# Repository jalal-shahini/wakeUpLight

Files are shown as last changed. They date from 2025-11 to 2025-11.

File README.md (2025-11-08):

# Wake up light

This is the circuit and code for a smart, super bight light that slowly brightens in the mornings to wake me up without an alarm.
The light can also be used as reading light at night with a timer to turn off automatically.
It features a 2004 LCD and a rotary encoder for user input.
The encoder has a calibrated debounce circuit and a schmitt-trigger for the cleanest possible signal.

An LED driver is required alongside this circuit.
I have decided to use a ZK-SJ20 to protect the LED from over current.
Max. LED power is 50 watts.
A CR2032 battery is required for the RTC to keep the time when the power is disconnected.

## To Do

* Since the device is connected to the wall outlet, energy efficiency was not of the highest concern. However, in feauture iterations, I will replace the linear voltage regulator with a buck converter.

**Disclaimer: The design is not yet ready for production. Therefore, the bom and positions files are not accurate.**

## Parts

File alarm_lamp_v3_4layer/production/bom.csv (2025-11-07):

Designator | Footprint | Quantity | Value | LCSC Part #
BT1 | BatteryHolder_MYOUNG_BS-07-A1BJ001_CR2032 | 1 | Battery_Cell | C5365915
C1, C10, C11, C2, C3, C4 | 0402 | 6 | 100 nF | C1525
C12 | 1206 | 1 | 2,2 uF | C50254
C5 | 0805 | 1 | 10 nF | C1710
C6, C7 | 0402 | 2 | 18 pF | C1549
C8 | 1206 | 1 | 22 uF | C1549
L1 | 0603 | 1 | 10 uH | C1035
R1 | 0603 | 1 | 330R | C23138
R10, R2, R6, R7, R8 | 0805 | 5 | 10 K | C17414
R11, R12, R3 | 0603 | 3 | 100K | C1002
R4, R5 | 0805 | 2 | 4.7k
R9 | 0805 | 1 | 100R | C17408
U1 | TQFP-32_7x7mm_P0.8mm | 1 | ATmega328P-A | C14877
U3 | SOIC-14_3.9x8.7mm_P1.27mm | 1 | 74HC14 | C5605
U4 | SOIC-16W_7.5x10.3mm_P1.27mm | 1 | DS3231M | C9866
U6 | WSON-10-1EP_2x3mm_P0.5mm_EP0.84x2.4mm_ThermalVias | 1 | TPS62177DQC | C91241
Y2 | Crystal_SMD_3225-4Pin_3.2x2.5mm | 1 | Crystal_GND24 | C2682774

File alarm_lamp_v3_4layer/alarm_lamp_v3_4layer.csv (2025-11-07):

Id | Designator | Footprint | Quantity | Designation | Supplier and ref
1 | BT1 | BatteryHolder_MYOUNG_BS-07-A1BJ001_CR2032 | 1 | Battery_Cell
2 | R4,R5 | R_0805_2012Metric | 2 | 4.7k
3 | R8,R10,R7,R2,R6 | R_0805_2012Metric | 5 | 10 K
4 | R12,R11,R3 | R_0603_1608Metric | 3 | 100K
5 | C11,C1,C4,C2,C10,C3 | C_0402_1005Metric | 6 | 100 nF
6 | C7,C6 | C_0402_1005Metric | 2 | 18 pF
7 | Y2 | Crystal_SMD_3225-4Pin_3.2x2.5mm | 1 | Crystal_GND24
8 | U1 | TQFP-32_7x7mm_P0.8mm | 1 | ATmega328P-A
9 | U4 | SOIC-16W_7.5x10.3mm_P1.27mm | 1 | DS3231M
10 | L1 | R_0402_1005Metric | 1 | 10 uH
11 | U6 | WSON-10-1EP_2x3mm_P0.5mm_EP0.84x2.4mm_ThermalVias | 1 | TPS62177DQC
12 | C12 | C_1206_3216Metric | 1 | 2,2 uF
13 | C5 | C_0805_2012Metric | 1 | 10 nF
14 | C8 | C_1206_3216Metric | 1 | 22 uF
15 | R9 | R_0805_2012Metric | 1 | 100R
16 | R1 | R_0603_1608Metric | 1 | 330R
17 | U3 | SOIC-14_3.9x8.7mm_P1.27mm | 1 | 74HC14

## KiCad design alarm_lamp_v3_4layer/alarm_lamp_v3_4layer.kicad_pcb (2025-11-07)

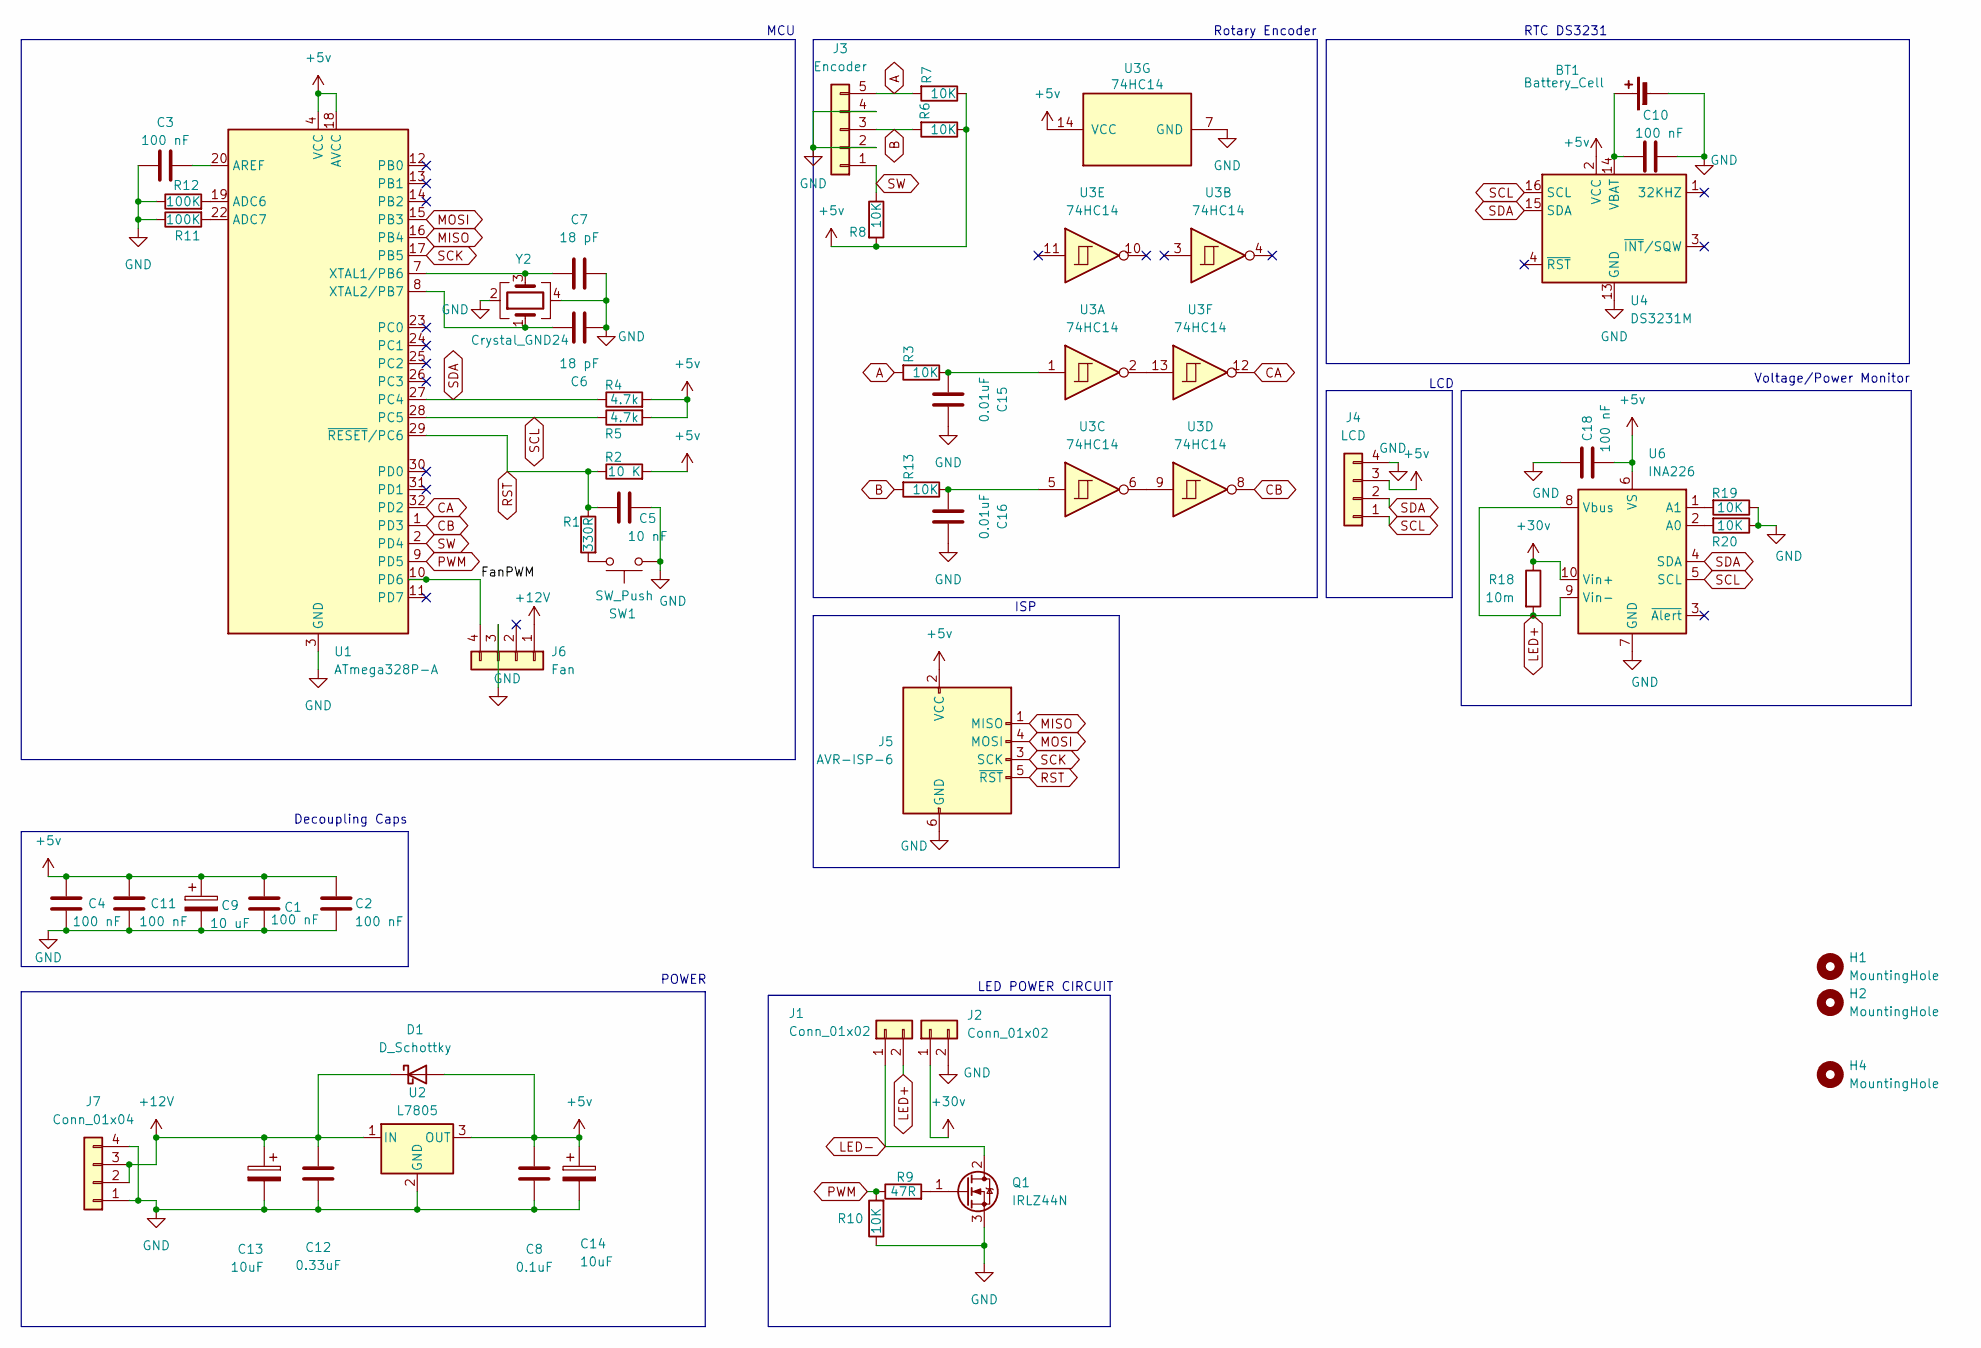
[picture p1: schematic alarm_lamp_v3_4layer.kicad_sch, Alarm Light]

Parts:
BT1: Battery_Cell; BatteryHolder_MYOUNG_BS-07-A1BJ001_CR2032; LCSC C5365915
C1, C4, C11, C18: 100 nF; C_0402_1005Metric; LCSC C1525
C2, C3: 100 nF; C_0603_1608Metric
C5: 10 nF; C_0603_1608Metric
C6, C7: 18 pF; C_0402_1005Metric; LCSC C1549
C8: 0.1uF; C_0603_1608Metric
C9: 10 uF; CP_Elec_4x5.3; LCSC C346925
C10: 100 nF; C_0402_1005Metric
C12: 0.33uF; C_0603_1608Metric
C13, C14: 10uF; CP_Elec_4x5.3; LCSC C346925
C15, C16: 0.01uF; C_0402_1005Metric
D1: D_Schottky; D_SOD-323; LCSC C191023
H1, H2, H4: MountingHole; MountingHole_3.2mm_M3
J1, J2: Conn_01x02; TerminalBlock_Phoenix_MKDS-1,5-2-5.08_1x02_P5.08mm_Horizont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
J3: Encoder; JST_XH_B5B-XH-A_1x05_P2.50mm_Vertical
J4: LCD; JST_XH_B4B-XH-A_1x04_P2.50mm_Vertical
J5: AVR-ISP-6; PinHeader_2x03_P2.54mm_Vertical
J6: Fan; JST_XH_B4B-XH-A_1x04_P2.50mm_Vertical
J7: Conn_01x04; TerminalBlock_Phoenix_MKDS-1,5-4-5.08_1x04_P5.08mm_Horizont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
Q1: IRLZ44N; TO-263-2; LCSC C19188232
R1: 330R; R_0603_1608Metric; LCSC C23138
R2: 10 K; R_0603_1608Metric; LCSC C17414
R3, R13: 10K; R_0402_1005Metric; LCSC C17414
R4, R5: 4.7k; R_0603_1608Metric
R6, R7, R8, R10: 10K; R_0603_1608Metric; LCSC C17414
R9: 47R; R_0603_1608Metric
R11, R12: 100K; R_0603_1608Metric; LCSC C25803
R18: 10m; R_2512_6332Metric
R19, R20: 10K; R_0603_1608Metric; LCSC C25804
SW1: SW_Push; SW_Push_1P1T_XKB_TS-1187A; LCSC C318884
U1: ATmega328P-A; TQFP-32_7x7mm_P0.8mm; LCSC C14877
U2: L7805; TO-263-2; LCSC C15077
U3: 74HC14; SOIC-14_3.9x8.7mm_P1.27mm; LCSC C5605
U4: DS3231M; SOIC-16W_7.5x10.3mm_P1.27mm; LCSC C9866
U6: INA226; VSSOP-10_3x3mm_P0.5mm; LCSC C2653835
Y2: Crystal_GND24; Crystal_SMD_3225-4Pin_3.2x2.5mm; LCSC C13738

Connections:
+5v: C1.1, C2.1, C4.1, C8.1, C9.1, C11.1, C14.1, C18.2, D1.2 (A), J4.3, J5.2 (VCC), R2.2, R4.2, R5.2, R6.1, R7.1, R8.2, U1.4 (VCC), U1.6 (VCC), U1.18 (AVCC), U2.3 (OUT), U3.14 (VCC), U4.2 (VCC), U6.6 (VS)
+12V: C12.1, C13.1, D1.1 (K), J6.1, J7.2, J7.3, U2.1 (IN)
+30v: J2.1, R18.1, U6.10 (Vin+)
/FanPWM: J6.4, U1.10 (PD6)
A: J3.5, R3.2, R7.2
B: J3.3, R6.2, R13.2
CA: U1.32 (PD2), U3.12
CB: U1.1 (PD3), U3.8
GND: BT1.2 (-), C1.2, C2.2, C3.2, C4.2, C5.2, C6.1, C7.1, C8.2, C9.2, C10.2, C11.2, C12.2, C13.2, C14.2, C15.1, C16.1, C18.1, J2.2, J3.2, J3.4, J4.4, J5.6 (GND), J6.3, J7.1, J7.4, Q1.3 (S), R10.1, R11.1, R12.1, R19.1, R20.1, SW1.2, U1.3 (GND), U1.5 (GND), U1.21 (GND), U2.2 (GND), U3.7 (GND), U4.5 (GND), U4.6 (GND), U4.7 (GND), U4.8 (GND), U4.9 (GND), U4.10 (GND), U4.11 (GND), U4.12 (GND), U4.13 (GND), U6.7 (GND), Y2.2, Y2.4
LED+: J1.2, R18.2, U6.8 (Vbus), U6.9 (Vin-)
LED-: J1.1, Q1.2 (D)
MISO: J5.1 (MISO), U1.16 (PB4)
MOSI: J5.4 (MOSI), U1.15 (PB3)
unnamed: BT1.1 (+), C10.1, U4.14 (VBAT)
unnamed: C15.2, R3.1, U3.1
unnamed: C16.2, R13.1, U3.5
unnamed: Q1.1 (G), R9.2
unnamed: R1.2, SW1.1
unnamed: R12.2, U1.19 (ADC6)
unnamed: R11.2, U1.22 (ADC7)
unnamed: C3.1, U1.20 (AREF)
unnamed: C7.2, U1.7 (XTAL1/PB6), Y2.3
unnamed: C6.2, U1.8 (XTAL2/PB7), Y2.1
unnamed: U3.6, U3.9
unnamed: U3.2, U3.13
unnamed: R20.2, U6.2 (A0)
unnamed: R19.2, U6.1 (A1)
PWM: R9.1, R10.2, U1.9 (PD5)
RST: C5.1, J5.5 (~RST), R1.1, R2.1, U1.29 (~RESET/PC6)
SCK: J5.3 (SCK), U1.17 (PB5)
SCL: J4.1, R5.1, U1.28 (PC5), U4.16 (SCL), U6.5 (SCL)
SDA: J4.2, R4.1, U1.27 (PC4), U4.15 (SDA), U6.4 (SDA)
SW: J3.1, R8.1, U1.2 (PD4)

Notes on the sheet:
POWER
LED POWER CIRCUIT
Rotary Encoder
LCD
RTC DS3231
Voltage/Power Monitor
ISP
Decoupling Caps
MCU

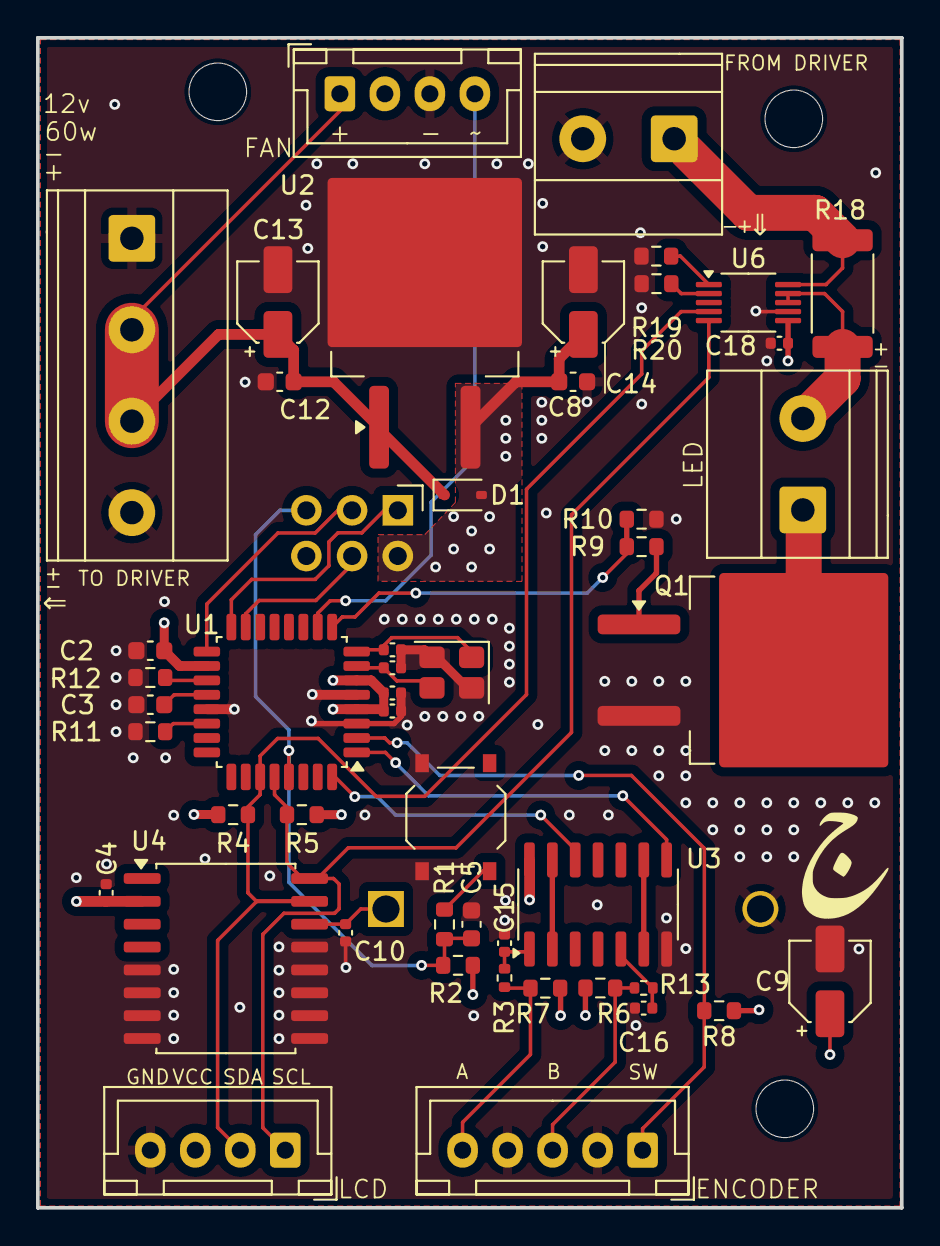
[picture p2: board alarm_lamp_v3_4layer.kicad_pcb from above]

Board: 4 copper layers, 48.0 x 65.0 mm, 53 parts (1 on the bottom side), 33 nets.
